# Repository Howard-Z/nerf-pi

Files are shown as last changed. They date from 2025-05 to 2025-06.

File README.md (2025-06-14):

# nerf-pi
UCLA Com Sci 188 - Introduction to Robotics, final project.

Our goal is to build a nerf "turret", consisting of a nerf gun on top of a rotating base and two cameras.  Binocular vision is implemented for the cameras to perceive depth and calculate rotation angles.  Two stepper motors are used to move the turret to the desired location, and shoot with a servo motor.

### Hardware
Hardware used in this include:
1. Nema 17 stepper motor
    - A4988 driver board
2. 28BYJ-48 stepper motor
    - ULN2003 driver board
3. SG90 servo motor
4. Nerf gun

The pins for each of the hardware components are defined inside of `turret.py`

An external 12v and 5v power supply are requred for eletronic device safety and smoother operation.

### Running
**Camera side**: run `binocular.py`.  This will start up the cameras, and any poses recorded will have the chest coordinate, as well as angle of rotations sent to the MQTT server.
- Environment: should be using python 3.10
```
mediapipe==0.10.21
opencv-python==4.6.0.66
```

**Turret side**: run `turret.py`.  This will receive input from the MQTT server, and pass the rotation angles into a PID controller, which will move the turret.
- Environment: Should be using python 3.12 or anything compatible with the following libraries:
```python
paho.mqtt
pid
RPi.GPIO
time
gpiozero
```

### Camera Calibration
To calibrate the two cameras, print out the checkerboard in `camera_calibration_checkerboard.pdf`, and take around 10-20 pictures with the checkerboard at different locations and angles within the camera frame.  Add those images to the calibration paths specified in `constants.py`.  Repeat for both cameras.  
* The positions of the checkerboard need not be the same between images for the two cameras.
* It is recommended to mount the checkerboard on a rigid surface (e.g., a picture frame, or cardboard) to ensure it is flat.
* Make sure the checkerboard is clearly and completely visible in each picture; not obscured, dark, washed out, or covered by shadows.  Smooth lighting is recommended.

### MQTT
The camera sends information to our turret platform using MQTT. We specify an MQTT broker within our 2 python files that allow data to be sent to the turret.

The topics that the turret is subscribed to are:
```python
TOPIC_MESSAGES = [
    "cam/ang/hor",
    "cam/ang/vert",
    "manual/override",
    "manual/hor",
    "manual/vert",
    "manual/trigger",
    "manual/level",
    "manual/center",
    "manual/arm",
    "manual/sentry"
]
```

Their descriptions are as follows:
- `manual/override`: Enable or disable manual control (disable or enable the robot policy) (1 or 0)
- `manual/hor`: manual horizontal movement of the base (integers pos/neg)
- `manual/vert`: manual vertical movement of the gun tilt (integers pos/neg)
- `manual/trigger`: manual actuation of the trigger servo (1)
- `manual/level`: Set the home level of the gun tilt stepper (1)
- `manual/center`: Set the home rotation of the base (1)
- `manual/arm`: Arm or disarm the robot (1 or 0)
    - signifies that the gun is either loaded (1) or unloaded (0)
- `manual/sentry`: Enables the policy to pull the trigger (1 or 0)
    - signifies if the trigger can be pulled by the automatic policy (1 for yes, 0 for no)
- `cam/ang/hor`: The angle relative to the camera that the targeted person is in the horizontal axis
- `cam/ang/vert`: The angle relative to the camera tht the targed person is in the vertical axis

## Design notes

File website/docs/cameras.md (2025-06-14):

# Camera Implementation

The primary objective of the camera module is to determine the angles in which to rotate the gun in order to point it at the person (if someone is present).  To do this, first, the world coordinate position of the person is needed, and from there, assuming the cameras are located at the origin, the angles can be calculated.  The angle calculation given the camera is present at the origin and the person is located at $(X, Y, Z)$, where $X$ is left/right position, $Y$ is the height, and $Z$ is the depth, is simply

$$
\begin{align*}
    \theta &= \tan^{-1}(\frac{X}{Z}) \\
    \phi &= \tan^{-1}(\frac{Y}{Z})
\end{align*}
$$

Here, $\theta$ represents the horizontal rotation of the gun to position the person at the center of the camera frame, and $\phi$ represents the vertical rotation.

To find the $(X, Y, Z)$ world coordinates, we used the point coordinates of the center of the chest $(x_1, y_1)$ and $(x_2, y_2)$, represented in the spaces of the left and right cameras, respectively, multiplied by the intrinsic matrix.  The intrinsic matrix is calculated by the camera calibration file.  The calibration matrices, $K_L$ and $K_R$ are approximately:

$$
\begin{align*}
    K_R &= \begin{bmatrix} 1401 & 0 & 9514 \\ 0 & 1400 & 481 \\ 0 & 0 & 1\end{bmatrix}\\
    K_L &= \begin{bmatrix} 1393 & 0 & 9222 \\ 0 & 1387 & 530 \\ 0 & 0 & 1\end{bmatrix}
\end{align*}
$$

From these, the focal lengths for each camera can be extracted.  This, with the distance between the two cameras, are used to calculate the depth (distance away from the camera) the person is standing.

```
def calculate_depth(K, point_L, point_R, dist_between_cams):
    x_disparity = point_L[0] - point_R[0]
    f_x = K[0, 0]

    depth = (f_x * dist_between_cams) / x_disparity
    return abs(depth)
```

$$
    Z = \frac{F_x \cdot d}{x_1 - x_2}
$$

$F_x$ is the horizontal focal length of the camera.  This method was used in the formula to calculate the world coordinates:

```
def calculate_world(K_L, K_R, point_L, point_R, dist_between_cams):
    _ZL = calculate_depth(K_L, point_L, point_R, dist_between_cams)
    _XL = _ZL * (point_L[0] - K_L[0, 2]) / K_L[0, 0] - (dist_between_cams / 2)
    _YL = _ZL * (point_L[1] - K_L[1, 2]) / K_L[1, 1]

    _ZR = calculate_depth(K_R, point_L, point_R, dist_between_cams)
    _XR = _ZR * (point_R[0] - K_R[0, 2]) / K_R[0, 0] - (dist_between_cams / 2)
    _YR = _ZR * (point_R[1] - K_R[1, 2]) / K_R[1, 1]

    return [(_XL + _XR) / 2, (_YL + _YR) / 2, (_ZL + _ZR) / 2]
```

Although only one camera may be used for this step, the averages of both cameras was used instead in case of one of the cameras being inaccurate.  Using the depth estimate, the $X$ and $Y$ coordinates can be estimated too.

$$
\begin{align*}
    X &= Z \cdot \frac{x - C_x}{F_x}\\
    Y &= Z \cdot \frac{y - C_y}{F_y}
\end{align*}
$$

$C_x$ and $C_y$ are the $x$ and $y$ of the principal point, and $F_x$ and $F_y$ are the horizontal and vertical focal lengths, respectively.

Now, the only part that is missing is the coordinates of the point of interest in the left and right cameras.  These are sourced from the media pipe module which gives a point estimate for 33 landmarks on the human body.  See [here](https://ai.google.dev/edge/mediapipe/solutions/vision/pose_landmarker).  The average of the points 11, 12, 23, and 24 gives a good estimate for the center of a person's chest, and was used for this project.

With this pipeline, a 2D point provided from each of the cameras can be translated into rotation angles for the turret to point at the correct location.

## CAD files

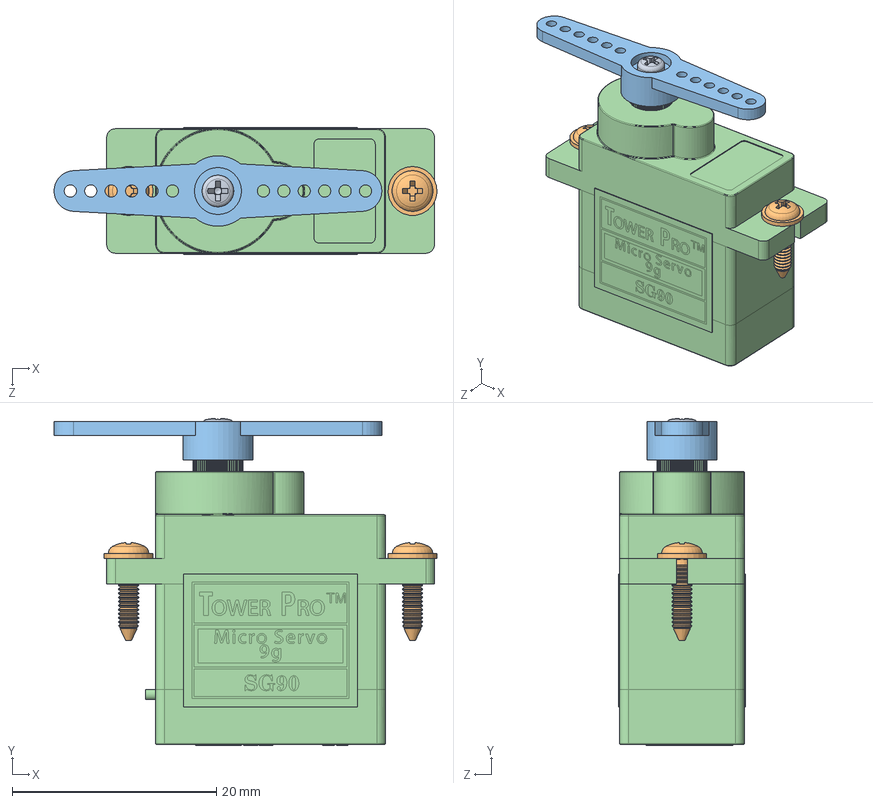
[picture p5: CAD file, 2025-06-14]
CAD_files/SG90 - Micro Servo 9g - Tower Pro.SLDASM
37.5 x 32.0 x 12.4 mm
SG90 - Micro Servo 9g - Tower Pro.1
SG90 - Micro Servo 9g - Tower Pro.3
SG90 - Micro Servo 9g - Tower Pro.5 x 2
SG90 - Micro Servo 9g - Tower Pro.6

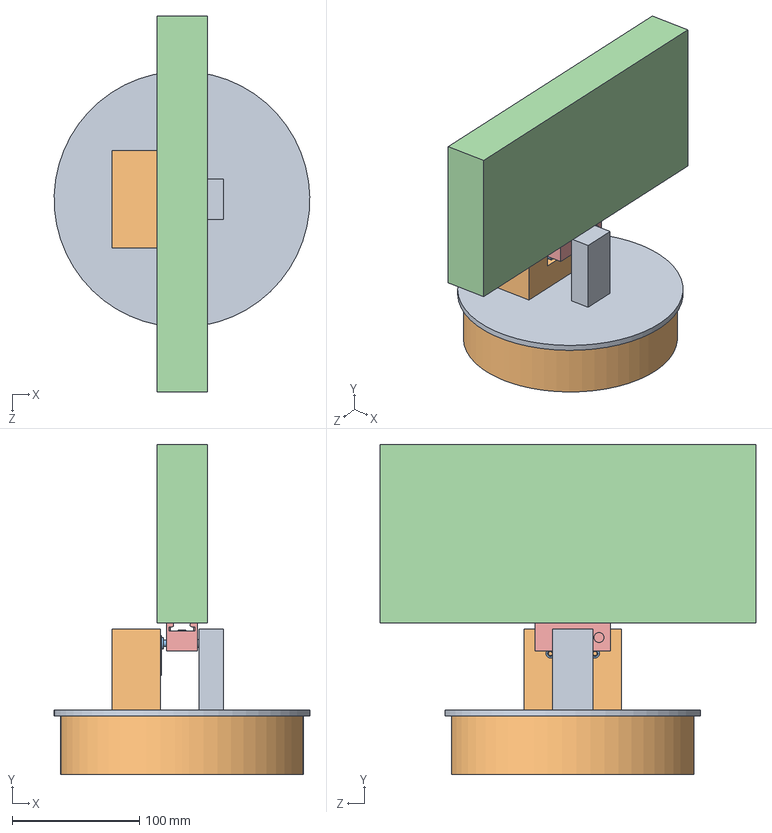
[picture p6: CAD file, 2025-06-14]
CAD_files/allTogether.SLDASM
200.6 x 258.9 x 295.0 mm
baseModel
lid
lidGear
motorGear
stepperMotor
betterMag
nerfGun
Stepper motor 28BYJ-48 5V
lidMotorBase
lidMotorBase-Sequel

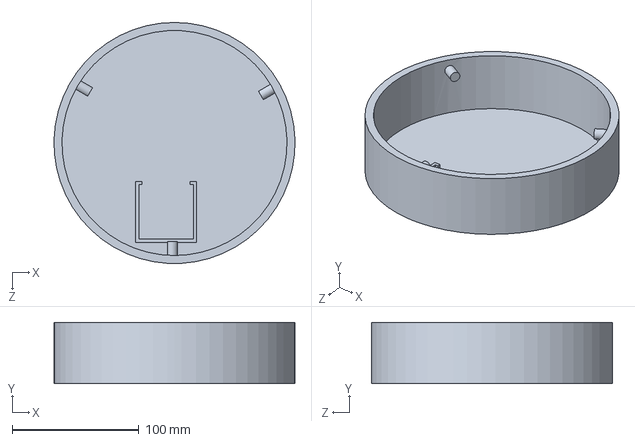
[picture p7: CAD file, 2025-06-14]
CAD_files/baseModel.SLDPRT
190.4 x 48.3 x 190.5 mm

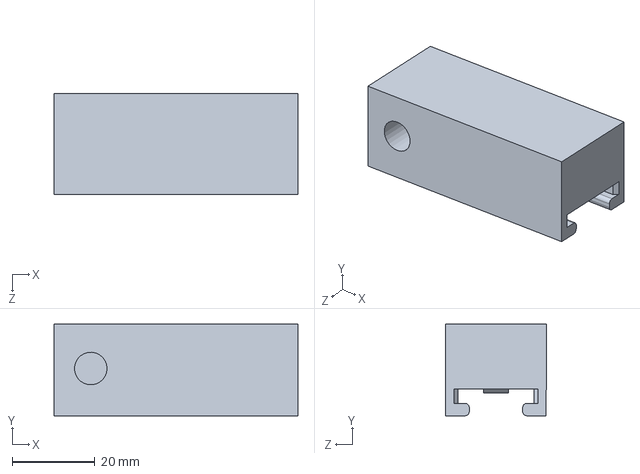
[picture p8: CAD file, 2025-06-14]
CAD_files/betterMag.SLDPRT
59.0 x 22.1 x 24.3 mm

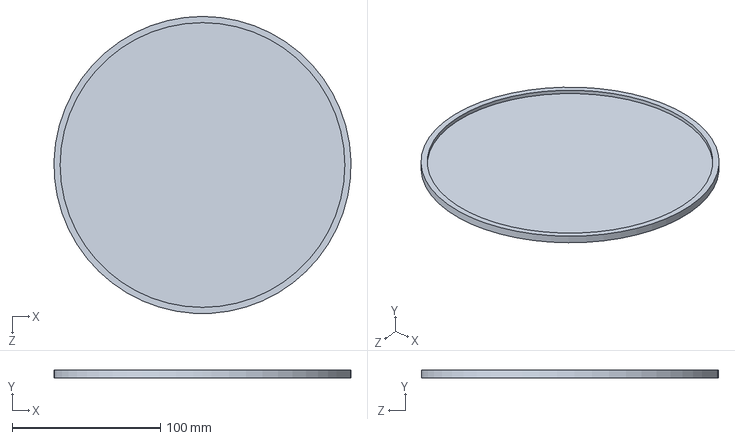
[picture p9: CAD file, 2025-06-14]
CAD_files/lid.SLDPRT
200.6 x 5.08 x 200.7 mm

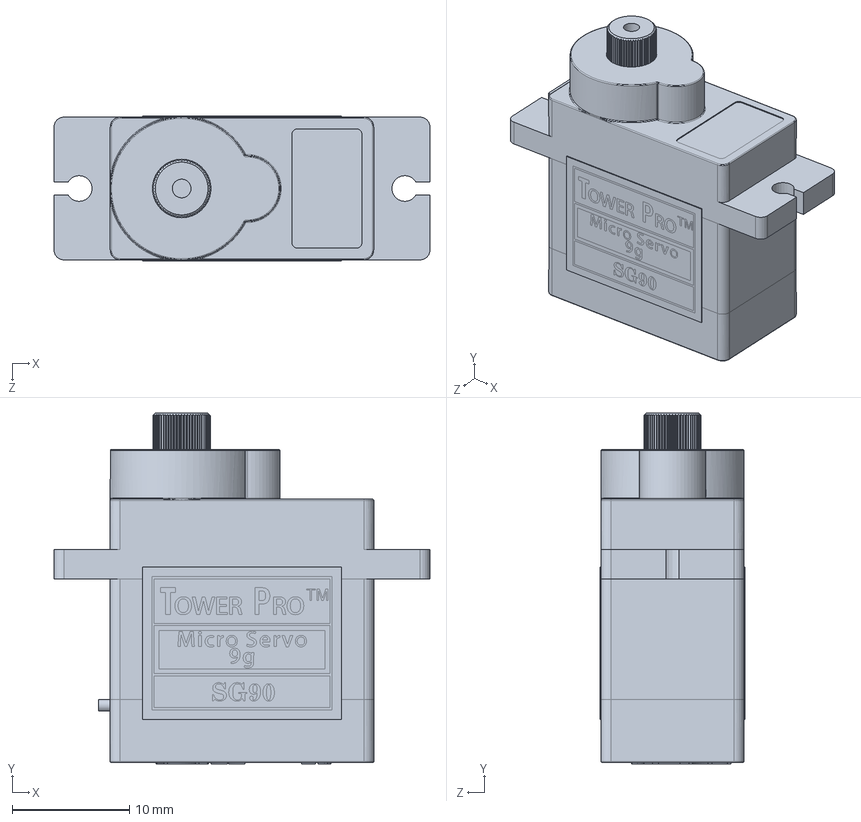
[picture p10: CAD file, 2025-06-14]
CAD_files/SG90 - Micro Servo 9g - Tower Pro.1.SLDPRT
32.1 x 30.0 x 12.4 mm

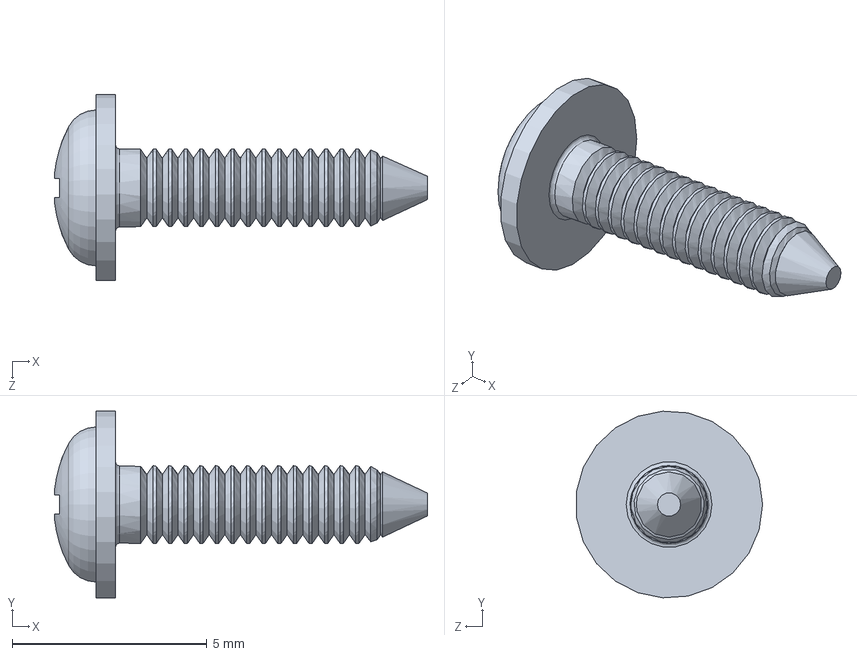
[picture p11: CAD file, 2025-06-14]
CAD_files/SG90 - Micro Servo 9g - Tower Pro.5.SLDPRT
9.57 x 4.79 x 4.78 mm

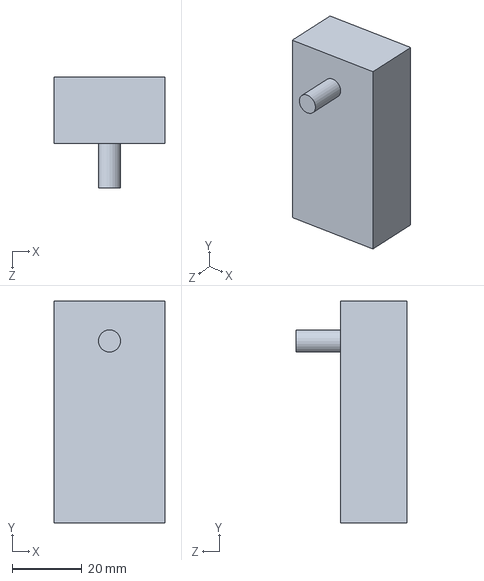
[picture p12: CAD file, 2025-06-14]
CAD_files/lidMotorBase-Sequel.SLDPRT
31.8 x 63.5 x 31.8 mm

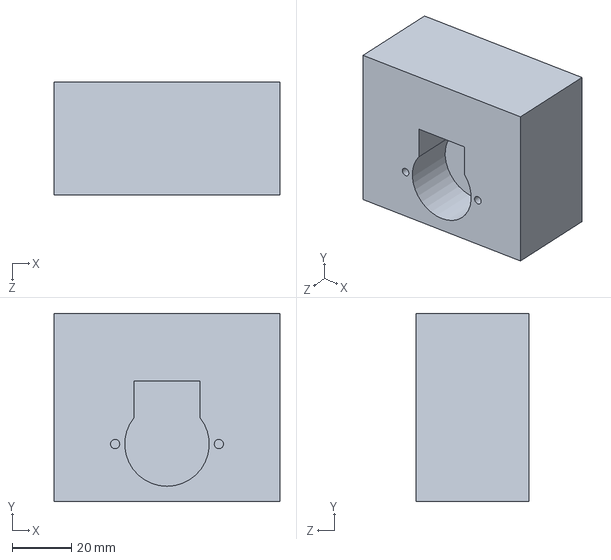
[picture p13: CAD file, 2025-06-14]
CAD_files/lidMotorBase.SLDPRT
76.2 x 63.5 x 38.1 mm

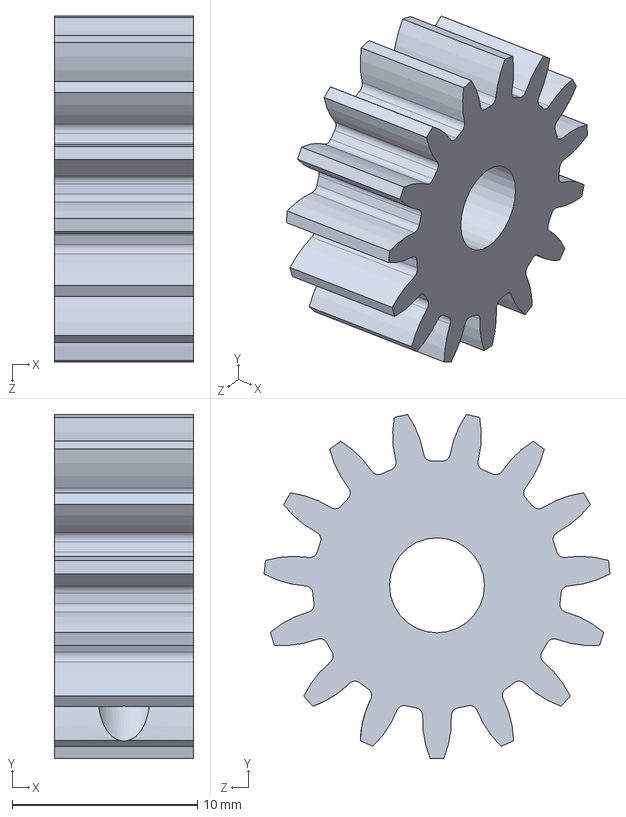
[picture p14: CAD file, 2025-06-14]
CAD_files/motorGear.SLDPRT
7.50 x 18.6 x 18.7 mm

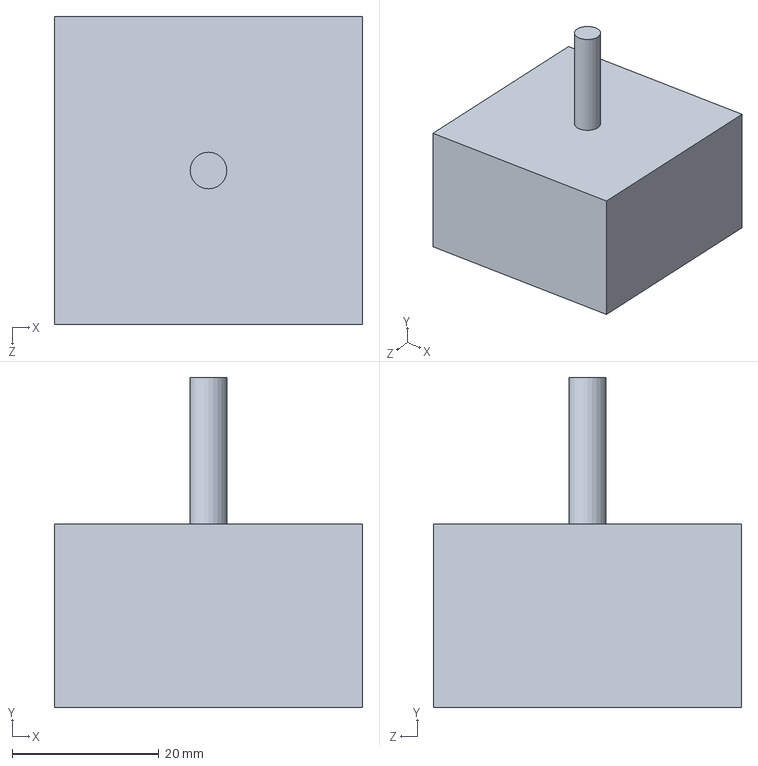
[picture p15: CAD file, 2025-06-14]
CAD_files/stepperMotor.SLDPRT
42.0 x 45.0 x 42.0 mm

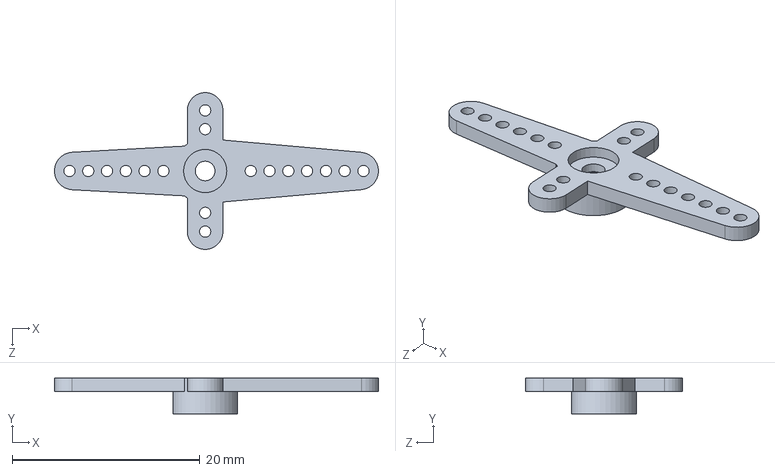
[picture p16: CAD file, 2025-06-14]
CAD_files/SG90 - Micro Servo 9g - Tower Pro.4.SLDPRT
34.5 x 3.80 x 16.7 mm

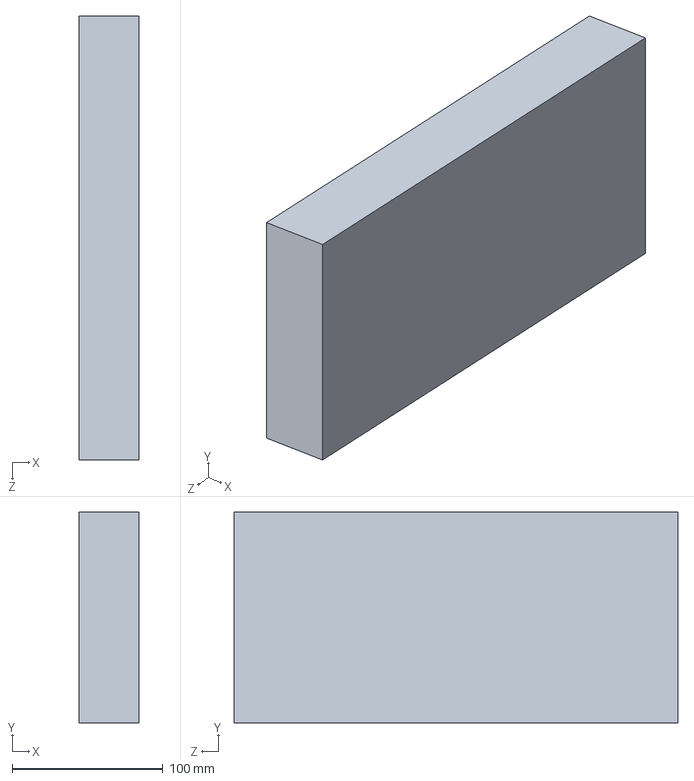
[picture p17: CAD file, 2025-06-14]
CAD_files/nerfGun.SLDPRT
40.0 x 140.0 x 295.0 mm

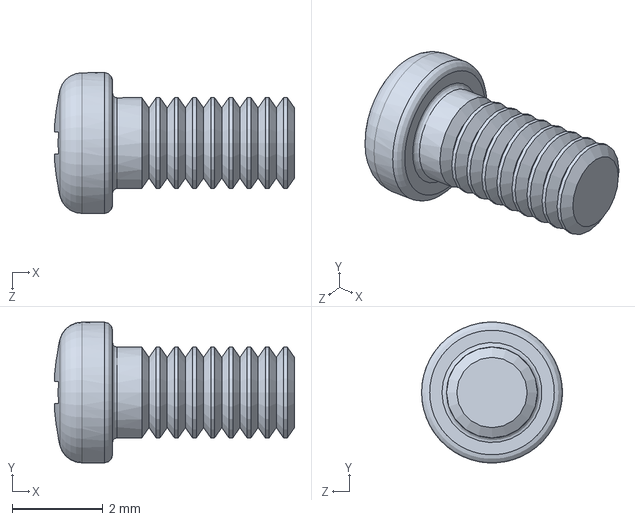
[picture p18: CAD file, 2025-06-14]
CAD_files/SG90 - Micro Servo 9g - Tower Pro.6.SLDPRT
5.28 x 3.10 x 3.10 mm

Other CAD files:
CAD_files/bModelSquare.SLDPRT
CAD_files/SG90 - Micro Servo 9g - Tower Pro.3.SLDPRT
CAD_files/lidGear.SLDPRT
CAD_files/Stepper motor 28BYJ-48 5V.SLDPRT
CAD_files/SG90 - Micro Servo 9g - Tower Pro.2.SLDPRT
CAD_files/SG90 - Micro Servo 9g - Tower Pro.x_t

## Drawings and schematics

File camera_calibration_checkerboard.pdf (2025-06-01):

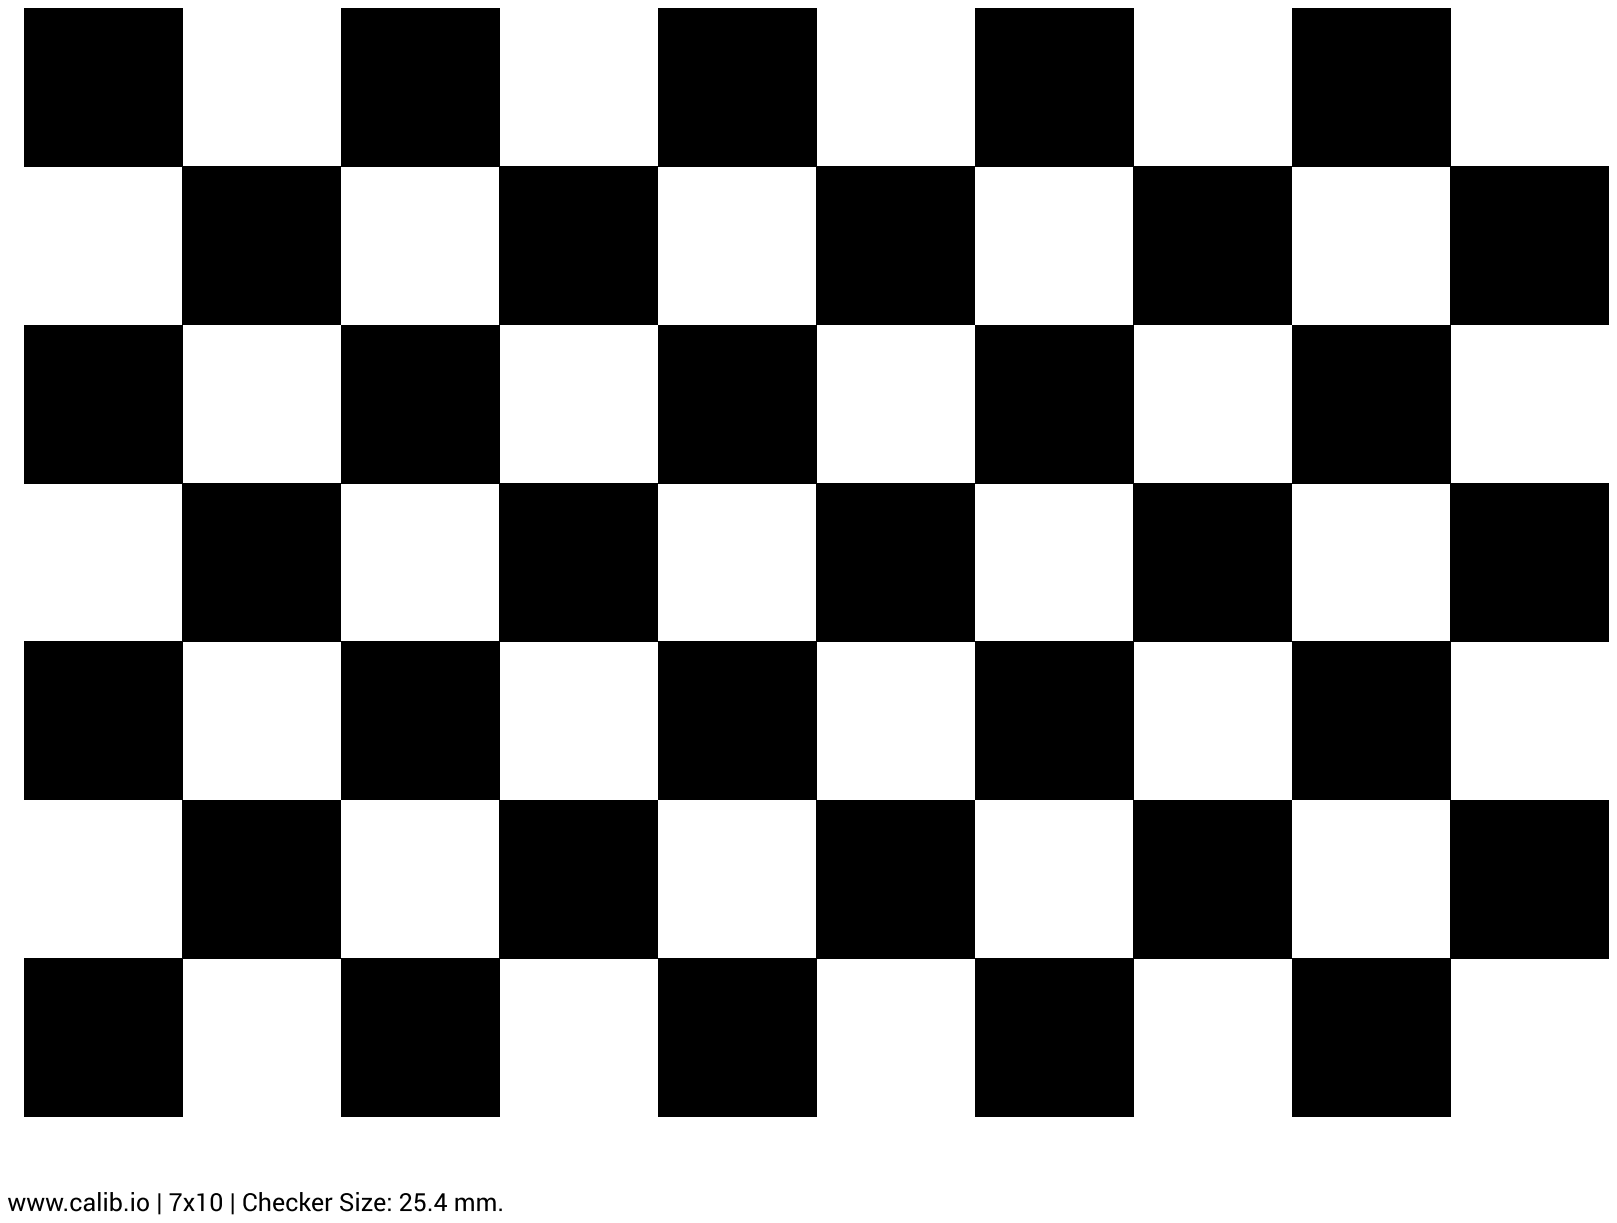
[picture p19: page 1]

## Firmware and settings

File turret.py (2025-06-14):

import paho.mqtt.client as mqtt
from pid import PID
import RPi.GPIO as GPIO
from time import sleep
import time
from gpiozero import Servo
from gpiozero.pins.pigpio import PiGPIOFactory

TOPIC_MESSAGES = [
    "cam/coord/x",
    "cam/coord/y",
    "cam/coord/z",
    "cam/ang/hor",
    "cam/ang/vert",
    "manual/override",
    "manual/hor",
    "manual/vert",
    "manual/trigger",
    "manual/level",
    "manual/center",
    "manual/arm",
    "manual/sentry"
]

BROKER = "192.168.1.158"  # Replace with your broker address
PORT = 1884                   # Standard MQTT port

factory = PiGPIOFactory()
PIN = 14
servo = Servo(PIN, pin_factory=factory,
              min_pulse_width=0.0005,  # 0.5ms
              max_pulse_width=0.0025)  # 2.5ms


# Use BCM GPIO numbering
DIR = 27     # Direction pin
STEP = 17    # Step pin
STEPS_PER_REV = 200  # 1.8° per step (typical for NEMA 17)
hor_pos = 0 # position in steps (aka 1.8 degrees)
vert_pos = 0
# 28byj pins (BCM)
in1 = 25
in2 = 8
in3 = 7
in4 = 1

# careful lowering this, at some point you run into the mechanical limitation of how quick your motor can move
step_sleep = 0.002

step_count = int(4096 * ( 5.0 / 360.0 )) # 5.625*(1/64) per step, 4096 steps is 360°

# direction = True # True for clockwise, False for counter-clockwise
                    # False for down, True for up

# defining stepper motor sequence (found in documentation http://www.4tronix.co.uk/arduino/Stepper-Motors.php)
step_sequence = [[1,0,0,1],
                 [1,0,0,0],
                 [1,1,0,0],
                 [0,1,0,0],
                 [0,1,1,0],
                 [0,0,1,0],
                 [0,0,1,1],
                 [0,0,0,1]]

# setting up
GPIO.setmode(GPIO.BCM)
GPIO.setup(DIR, GPIO.OUT)
GPIO.setup(STEP, GPIO.OUT)

# GPIO.setmode( GPIO.BCM )
GPIO.setup( in1, GPIO.OUT )
GPIO.setup( in2, GPIO.OUT )
GPIO.setup( in3, GPIO.OUT )
GPIO.setup( in4, GPIO.OUT )

# initializing
GPIO.output( in1, GPIO.LOW )
GPIO.output( in2, GPIO.LOW )
GPIO.output( in3, GPIO.LOW )
GPIO.output( in4, GPIO.LOW )

motor_pins = [in1,in2,in3,in4]
motor_step_counter = 0

manual_override = True

hor_target = 0.0
ver_target = 0.0

armed = False
sentry = False
data_flag = False

def step_motor_rev(revolutions, direction=True, delay=0.0008): #0004 is fastest
    GPIO.output(DIR, direction)
    steps = int(STEPS_PER_REV * revolutions)
    for _ in range(steps):
        GPIO.output(STEP, GPIO.HIGH)
        sleep(delay)
        GPIO.output(STEP, GPIO.LOW)
        sleep(delay)
        
def step_motor_deg(degrees, direction=True, delay=0.0008): #0004 is fastest
    GPIO.output(DIR, direction)
    steps = (degrees * 85.0 / 15.0) / 1.8
    for _ in range(int(steps)):
        GPIO.output(STEP, GPIO.HIGH)
        sleep(delay)
        GPIO.output(STEP, GPIO.LOW)
        sleep(delay)

def step_motor(steps, direction=True, delay=0.0008): #0004 is fastest
    GPIO.output(DIR, direction)
    global hor_pos
    # positive is clockwise
    # True is clockwise
    # print("attempt to step motor: ", steps)
    # print("hor_pos: ", hor_pos)
    # print("direction: ", direction)
    if abs(steps) < 2:
        return
    if hor_pos >= 720 and direction: #1440 is for 8th step +- 180 deg
        return
    if hor_pos <= -720 and not direction:
        return
    for _ in range(int(steps)):
        GPIO.output(STEP, GPIO.HIGH)
        sleep(delay)
        GPIO.output(STEP, GPIO.LOW)
        sleep(delay)
    if direction:
        hor_pos += int(steps * 1.8 * 15.0 / 85.0)
    else:
        hor_pos -= int(steps * 1.8 * 15.0 / 85.0)

def goto_tilt(degrees):
    global vert_pos
    global motor_step_counter
    global motor_pins
    global step_sequence
    global in1, in2, in3, in4

    limit = 10
    # target_angle = max(-limit, min(limit, degrees - vert_pos))
    # print("target_angle: ", target_angle, "vert_pos: ", vert_pos)
    # diff = target_angle - vert_pos
    if degrees > limit:
        degrees = limit
    elif degrees < -limit:
        degrees = -limit
    target_angle = degrees - vert_pos
    diff = target_angle
    steps = int(4096 * (abs(diff) / 360.0))
    direction = diff > 0
    steps = abs(steps)
    # print("current position: ", vert_pos, "deg requested: ", degrees, "target_angle: ", target_angle)
    # print("stepping: ", steps, " direction: ", direction, " diff: ", diff)
    vert_pos = vert_pos + diff
    # the meat
    i = 0
    for i in range(steps):
        for pin in range(0, len(motor_pins)):
            GPIO.output( motor_pins[pin], step_sequence[motor_step_counter][pin] )
        if direction==False:
            motor_step_counter = (motor_step_counter - 1) % 8
        elif direction==True:
            motor_step_counter = (motor_step_counter + 1) % 8
        else: # defensive programming
            print( "uh oh... direction should *always* be either True or False" )
            GPIO.cleanup()
            exit( 1 )
        time.sleep( step_sleep )
    GPIO.output( in1, GPIO.LOW )
    GPIO.output( in2, GPIO.LOW )
    GPIO.output( in3, GPIO.LOW )
    GPIO.output( in4, GPIO.LOW )

def trigger():
    global servo
    print("FIREEE")
    print("Rotating to +90°")
    servo.max()
    sleep(1)

    # print("Rotating to -90°")
    # servo.min()
    # sleep(1)

    print("Center (0°)")
    servo.mid()
    sleep(1)

    print("Rotating to +90°")
    servo.max()
    sleep(1)



# The callback for when the client receives a CONNACK response from the server.
def on_connect(client, userdata, flags, reason_code, properties):
    print(f"Connected with result code {reason_code}")
    # Subscribing in on_connect() means that if we lose the connection and
    # reconnect then subscriptions will be renewed.
    for topic in TOPIC_MESSAGES:
        client.subscribe(topic)

# The callback for when a PUBLISH message is received from the server.
def on_message(client, userdata, msg):
    global manual_override
    global hor_pos
    global hor_pid
    global vert_pid
    global vert_pos
    global hor_target
    global ver_target
    global armed
    global sentry
    global data_flag
    # print(msg.topic+" "+msg.payload.decode())
    if msg.topic == "manual/override":
        if msg.payload.decode() == "1":
            print("Manual mode")
            manual_override = True
            hor_pid.reset([0.0])
            vert_pid.reset([0.0])
        elif msg.payload.decode() == "0":
            print("Automated mode")
            manual_override = False
        else:
            print("Uknown command, defualt to manual")
            manual_override = True
    elif msg.topic == "manual/hor":
        if manual_override:
            deg_rot = float(msg.payload.decode())
            if deg_rot > 0:
                print(f"Rotate horizontal CW by {deg_rot} degrees")
                step_motor_deg(deg_rot, direction=True)
                hor_pos += int(deg_rot)
            elif deg_rot < 0:
                print(f"Rotate horizontal CCW by {deg_rot} degrees")
                step_motor_deg(-1 * deg_rot, direction=False)
                hor_pos += int(deg_rot)
            else:
                print("Unknown command for horizontal rotation")
    elif msg.topic == "manual/vert":
        if manual_override:
            deg_rot = float(msg.payload.decode())
            print("tilting to: ", deg_rot)
            goto_tilt(deg_rot)
            vert_pos = deg_rot
    elif msg.topic == "manual/level":
        if manual_override:
            if msg.payload.decode() == "1":
                print("setting current position as level")
                vert_pos = 0
                vert_pid.reset([0.0])
    elif msg.topic == "manual/center":
            if msg.payload.decode() == "1":
                print("setting current position as the center")
                hor_pos = 0
                hor_pid.reset([0.0])
    elif msg.topic == "manual/trigger":
        if msg.payload.decode() == "1":
            print("Firing!")
            trigger()
    elif msg.topic == "cam/ang/hor":
        if not manual_override:
            deg_target = float(msg.payload.decode())
            print("deg_target: ", deg_target)
            # hor_pid.reset([deg_target]) # maybe use set_target instead?
            hor_pid.set_target([deg_target])
            hor_target = deg_target
            data_flag = True
    elif msg.topic == "cam/ang/vert":
        if not manual_override:
            deg_target = float(msg.payload.decode())
            # vert_pid.reset([deg_target]) # maybe use set_target instead?
            vert_pid.set_target([deg_target])
            ver_target = deg_target
    elif msg.topic == "manual/arm":
        if msg.payload.decode() == "1":
            print("Arming turret")
            armed = True
        elif msg.payload.decode() == "0":
            print("Disarming turret")
            armed = False
    elif msg.topic == "manual/sentry":
        if msg.payload.decode() == "1":
            print("Sentry mode enabled")
            sentry = True
        elif msg.payload.decode() == "0":
            print("Sentry mode disabled")
            sentry = False
        
        
        
mqttc = mqtt.Client(mqtt.CallbackAPIVersion.VERSION2)
mqttc.on_connect = on_connect
mqttc.on_message = on_message

mqttc.connect("192.168.1.158", 1884, 60)

hor_pid = PID(kp=0.6, ki=0.1, kd=1.0, target=[0.0])
vert_pid = PID(kp=0.6, ki=0.1, kd=1.0, target=[0.0])

loop_dt = .005
hor_dt = .01
vert_dt = .01

if __name__ == "__main__":
    print("Connecting to MQTT broker...")
    mqttc.connect("192.168.1.158", 1884, 60)
    print("Connected! Starting loop")
    mqttc.loop_start()
    prev_time = 0


    try:
        while True:

            # mqttc.publish("status/theta_pos", hor_pos)
            sleep(loop_dt)
            # hor_update = hor_pid.update(hor_pos, hor_dt)[0] #update hor_pos to 0
            # vert_update = vert_pid.update(vert_pos, vert_dt)[0] #update vert_pos to 0
            hor_update = hor_pid.update(0, hor_dt)[0]
            vert_update = vert_pid.update(vert_pos, vert_dt)[0]
            # print("looping")
            if not manual_override:
                if hor_update > 0:
                    # print(f"PID horizontal control: Rotate CW by {hor_update} degrees")
                    # step_motor(abs(hor_update), direction=True)
                    # step_motor(5, True)
                    # hor_pos += int(hor_update)
                    pass
                elif hor_update < 0:
                    # print(f"PID horizontal control: Rotate CCW by {hor_update} degrees")
                    # step_motor(abs(hor_update), direction=False)
                    # step_motor(5, False)
                    # hor_pos += int(hor_update)
                    pass
                else:
                    # print("No horizontal PID control needed")
                    pass
                goto_tilt(ver_target)
                if hor_target > 0:
                    step_motor_deg(hor_target, direction=True)
                elif hor_target < 0:
                    step_motor_deg(-hor_target, direction=False)

                # print("hor_target: ", hor_target, "armed: ", armed, "sentry: ", sentry, "data flag: ", data_flag)
                if abs(hor_target) < 2 and armed and sentry and data_flag:
                    trigger()
                    armed = False
                    sentry = False
                    mqttc.publish("manual/sentry", "0")
                    mqttc.publish("manual/arm", "0")


                hor_target = 0

                
                # Vertical control logic can be added here
                # if vert_update > 0 or vert_update < 0:
                #     step_motor_deg(vert_update / 360, direction=(vert_update > 0))
            else:
                # print("Manual override active, skipping PID control")
                pass
            if manual_override:
                pass
            cur_time = time.time()
            if cur_time - prev_time >= 1:
                prev_time = cur_time
                # Publish status to MQTT broker
                mqttc.publish("status/hor_pos", hor_pos)
                mqttc.publish("status/vert_pos", vert_pos)
            data_flag = False
            
                
    except KeyboardInterrupt:
        print("Disconnecting from MQTT broker...")
        mqttc.loop_stop()
        mqttc.disconnect()
        servo.detach()
        GPIO.output( in1, GPIO.LOW )
        GPIO.output( in2, GPIO.LOW )
        GPIO.output( in3, GPIO.LOW )
        GPIO.output( in4, GPIO.LOW )
        GPIO.cleanup()
        print("Disconnected.")

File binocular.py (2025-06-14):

import signal
import sys

from pose_landmarker import initialize_landmarker, data_lock, shared_data
from constants import CAMERA_DIST, FUDGE, MAX_CHANGE, POI_INDEX
from numpy import load, array
import threading
import time
import math

import paho.mqtt.client as mqtt
from paho.mqtt.client import Client, CallbackAPIVersion

# MQTT broker configuration
BROKER = "192.168.1.158"  # Replace with your broker address
PORT = 1884                   # Standard MQTT port
# Dictionary of topics and their messages
TOPIC_MESSAGES = [
    "cam/coord/x",
    "cam/coord/y",
    "cam/coord/z",
    "cam/ang/hor",
    "cam/ang/vert"
]
CLIENT_ID = "camera-node"

# Callback when the client connects to the broker
def on_connect(client, userdata, flags, reason_code, properties):
    print(f"Connected with result code {reason_code}")


# https://ai.google.dev/edge/mediapipe/solutions/vision/pose_landmarker


shutdown_event = threading.Event()

def start_cameras():
    thread1 = threading.Thread(target=initialize_landmarker, args=(0, True, shutdown_event))
    thread2 = threading.Thread(target=initialize_landmarker, args=(1, False, shutdown_event))
    thread1.start()
    thread2.start()
    return [thread1, thread2]


def calculate_depth(K, point_L, point_R, dist_between_cams):
    x_disparity = point_L[0] - point_R[0]
    f_x = K[0, 0]

    depth = (f_x * dist_between_cams) / x_disparity
    return abs(depth) * FUDGE(abs(depth))     # positive is in front of the cameras.


def calculate_world(K_L, K_R, point_L, point_R, dist_between_cams):
    _ZL = calculate_depth(K_L, point_L, point_R, dist_between_cams)
    _XL = _ZL * (point_L[0] - K_L[0, 2]) / K_L[0, 0] - (dist_between_cams / 2)
    _YL = _ZL * (point_L[1] - K_L[1, 2]) / K_L[1, 1]

    _ZR = calculate_depth(K_R, point_L, point_R, dist_between_cams)
    _XR = _ZR * (point_R[0] - K_R[0, 2]) / K_R[0, 0] - (dist_between_cams / 2)
    _YR = _ZR * (point_R[1] - K_R[1, 2]) / K_R[1, 1]

    # print(_XL, _YL, _ZL)
    # print(_XR, _YR, _ZR)

    return [(_XL + _XR) / 2, (_YL + _YR) / 2, (_ZL + _ZR) / 2]


if __name__ == '__main__':
    # load camera calibration file.  (Generated with camera_calibration.py)
    # Fields: "ret_L", "K_L", "dist_L", "rvecs_L", "tvecs_L", "objpoints_L", "imgpoints_L"
    #         "ret_R", "K_R", "dist_R", "rvecs_R", "tvecs_R", "objpoints_R", "imgpoints_R"
    print("Connecting to MQTT Broker: ", BROKER)
    print("Using port: ", PORT)
    
    mqttc = mqtt.Client(mqtt.CallbackAPIVersion.VERSION2)
    mqttc.on_connect = on_connect
    # mqttc.on_message = on_message
    # Connect and start loop
    mqttc.connect(BROKER, PORT, 60)
    mqttc.loop_start()
    time.sleep(1)  # Allow time for connection
    print("Publishing to: ", TOPIC_MESSAGES)

    # Publish to each topic
    # for topic, message in TOPIC_MESSAGES.items():
    #     result = mqttc.publish(topic, message)
    #     status = result[0]
    #     if status == 0:
    #         print(f"📤 Sent `{message}` to `{topic}`")
    #     else:
    #         print(f"⚠️ Failed to send to {topic}")

    calibration = load("./calibration.npy", allow_pickle=True).item()

    calculate_world_curry = lambda lp, rp: calculate_world(
        calibration["K_L"], calibration["K_R"], lp, rp, CAMERA_DIST)
    
    started = False
    try:
        camera_threads = start_cameras()
        current = None
        while True:
            if shutdown_event.is_set():
                break
            with data_lock:
                left = shared_data[0]
                right = shared_data[1]

            if left and right and left[1] and right[1]:
                left[1].append(array([left[1][11], left[1][12], left[1][23], left[1][24]]).mean(axis=0))
                right[1].append(array([right[1][11], right[1][12], right[1][23], right[1][24]]).mean(axis=0))
                points = list(map(calculate_world_curry, left[1], right[1]))
                started = True
            else:
                points = []

            if not started:
                time.sleep(1)
                continue

            if not points:
                print("No pose detected.")
                time.sleep(1)
                continue

            # print("------------------------------------------")
            # for n, i in enumerate(points):
            #     print(f"{n}: ({i[0]}, {i[1]}, {i[2]})")
            
            if not current:
                current = points[POI_INDEX]
            
            for i in range(3):
                current[i] = points[POI_INDEX][i] if abs(current[i] - points[POI_INDEX][i]) < MAX_CHANGE else \
                            current[i] - MAX_CHANGE if points[POI_INDEX][i] < current[i] else \
                            current[i] + MAX_CHANGE

            print(current)

            result = mqttc.publish(TOPIC_MESSAGES[0], current[0])
            result = mqttc.publish(TOPIC_MESSAGES[1], current[1])
            result = mqttc.publish(TOPIC_MESSAGES[2], current[2])

            theta = math.atan(current[0]/current[2])
            phi = math.atan(current[1]/current[2])

            result = mqttc.publish(TOPIC_MESSAGES[3], theta * 180 / math.pi)
            result = mqttc.publish(TOPIC_MESSAGES[4], phi * 180 / math.pi)
            
            time.sleep(.2)

    except KeyboardInterrupt:
        shutdown_event.set()
        print("\n🛑 Ctrl+C detected. Shutting down gracefully...")

    finally:
        for t in camera_threads:
            t.join()
        mqttc.loop_stop()
        mqttc.disconnect()
        print("🔌 MQTT client disconnected. Exiting.")
        # sys.exit(0)

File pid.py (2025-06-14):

import numpy as np

class PID:
    def __init__(self, kp, ki, kd, target):
        """
        Initialize a variable-dimension PID controller.

        Args:
            kp (float or list): Proportional gain(s) per axis (or scalar).
            ki (float or list): Integral gain(s) per axis (or scalar).
            kd (float or list): Derivative gain(s) per axis (or scalar).
            target (tuple or array): Target position of any dimension.
        """
        self.setpoint = np.array(target, dtype=np.float64)
        dim = self.setpoint.shape[0]

        self.kp = np.array(kp if hasattr(kp, '__len__') else [kp] * dim, dtype=np.float64)
        self.ki = np.array(ki if hasattr(ki, '__len__') else [ki] * dim, dtype=np.float64)
        self.kd = np.array(kd if hasattr(kd, '__len__') else [kd] * dim, dtype=np.float64)

        self._prev_error = np.zeros(dim)
        self._integral = np.zeros(dim)
        
    def set_target(self, target = None):
        """
        Set a new target for the PID controller.

        Args:
            target (tuple or array, optional): New target position.
        """
        if target is not None:
            self.setpoint = np.array(target, dtype=np.float64)
            dim = self.setpoint.shape[0]

    def reset(self, target=None):
        """
        Reset the internal state of the PID controller.

        Args:
            target (optional): New target to reset to.
        """
        if target is not None:
            self.setpoint = np.array(target, dtype=np.float64)
            dim = self.setpoint.shape[0]
            self._prev_error = np.zeros(dim)
            self._integral = np.zeros(dim)
        else:
            self._prev_error.fill(0)
            self._integral.fill(0)

    def get_error(self):
        """
        Returns:
            float: Magnitude of the last error vector.
        """
        return np.linalg.norm(self._prev_error)

    def update(self, current_pos, dt):
        """
        Compute the PID control signal.

        Args:
            current_pos (array-like): Current position (any dimension).
            dt (float): Time delta in seconds.

        Returns:
            np.ndarray: Control output vector.
        """
        current_pos = np.array(current_pos, dtype=np.float64)
        error = self.setpoint - current_pos

        self._integral += error * dt
        derivative = (error - self._prev_error) / dt if dt > 0 else np.zeros_like(error)

        output = (
            self.kp * error +
            self.ki * self._integral +
            self.kd * derivative
        )

        self._prev_error = error
        return output

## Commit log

2025-06-10 Updated website to include documentation for the camera math.
2025-06-14 CAD Files
    Contains all Solidworks Assembly and Part files
    [SG90 - Micro Servo 9g - Tower Pro.1.SLDPRT, SG90 - Micro Servo 9g - Tower Pro.2.SLDPRT, SG90 - Micro Servo 9g - Tower Pro.3.SLDPRT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]
